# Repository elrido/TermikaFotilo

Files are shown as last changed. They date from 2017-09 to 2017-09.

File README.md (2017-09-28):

Termika Fotilo
==============

Termika Fotilo is Esperanto for thermal camera. The project, published in
[Make: Magazin 3/2017 on page 16](https://www.heise.de/select/make/2017/3/1498421900241703), 
describes a very limited infrared camera based on the relatively cheap (around
EUR 40) Melexis MLX90621 infrared sensor with a resolution of 16x4 pixels.

Origin
------

This is in turn inspired by the [DIY-Thermocam of Max Ritter](http://www.diy-thermocam.net/)
which was presented on the Maker Faire 2016 in Berlin. Ritter's kit uses a Flir
Lepton 3 infrared sensor with a resolution of 160x120 pixels (with a Lepton 2.5
the resolution is 80x60). That sensor is a lot better, but also much more expensive.

Finally, this repository aims to port the Termika Fotilo sketchbook, written for
use with an Arduino Nano, over to the ESP8266 plattform. It may be used with so
called dev boards, like the NodeMCU, which already comes with a voltage regulator
for a powering over USB or a battery pack, but these files are provided with use
of a bare ESP-12-E or ESP-12-F in mind (ESP-7 or earlier ESP-12 revisions should
work, but are untested: check your pinout diagrams).

Motivation
----------

If you do have a Arduino Nano at hand, then please just go for the Make: Magazin
article, which has very detailed instructions how to set up and may be purchased
for just EUR 3.29 as a PDF, in case you do not own that issue of the magazine.

The reason I am using an ESP chip instead is simply because I have them
already lying around, they are dirt cheap (currently around USD 1.70) and even
more compact then an Arduino Nano. The downside is that when using a bare ESP we
do have to add a few components for getting some pins to the right level on boot,
for voltage stability and of course the whole WiFi part of the ESP goes completely
unused.

Schema
------

Here below is schema showing how to set this up with a bare, flashed ESP chip.
When using a NodeMCU, the schema from the Make: article can be applied,
obviously choosing the appropriate SPI- and I²C-pins of the NodeMCU.

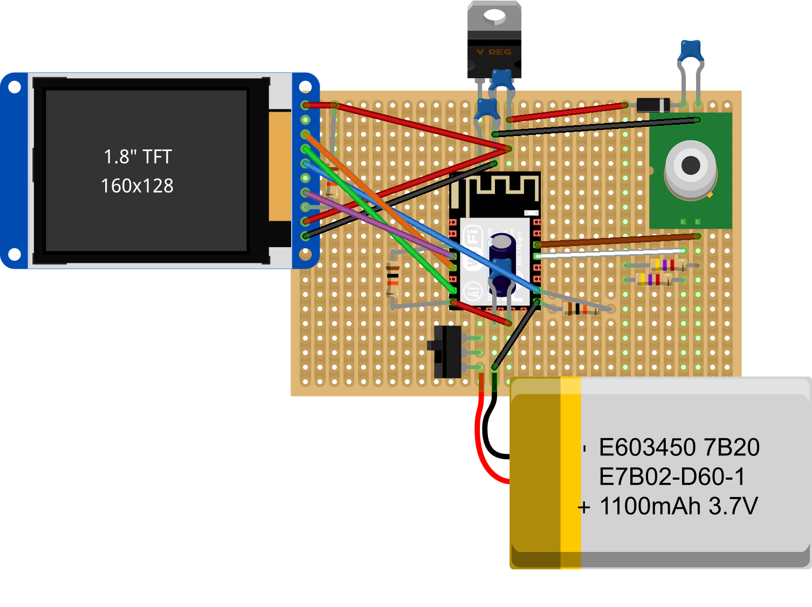
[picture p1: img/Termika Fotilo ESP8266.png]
Termika Fotilo schema using an ESP8266


Result
------

Backside before soldering on the screen:

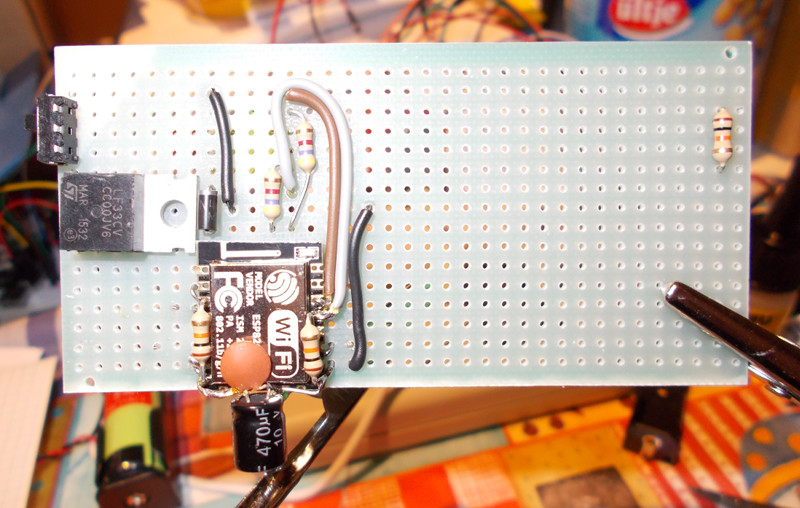
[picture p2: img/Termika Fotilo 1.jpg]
Termika Fotilo backside before soldering on the screen


Backside with screen soldered on:

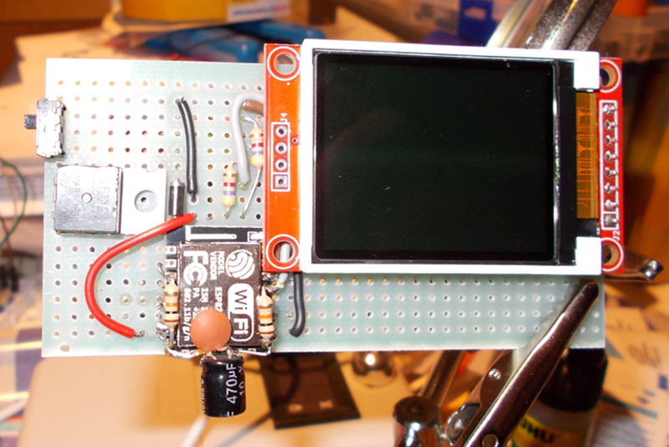
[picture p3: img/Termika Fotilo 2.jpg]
Termika Fotilo backside with screen soldered on


Front before attaching the battery:

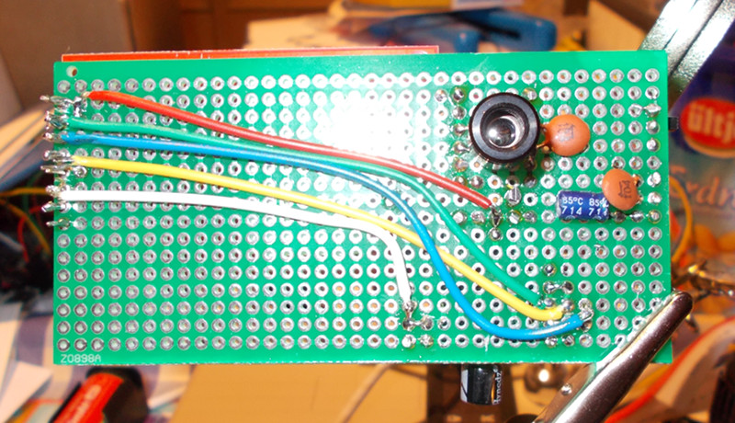
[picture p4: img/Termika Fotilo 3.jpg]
Termika Fotilo front before attaching the battery


Front with battery and USB charging board attached:

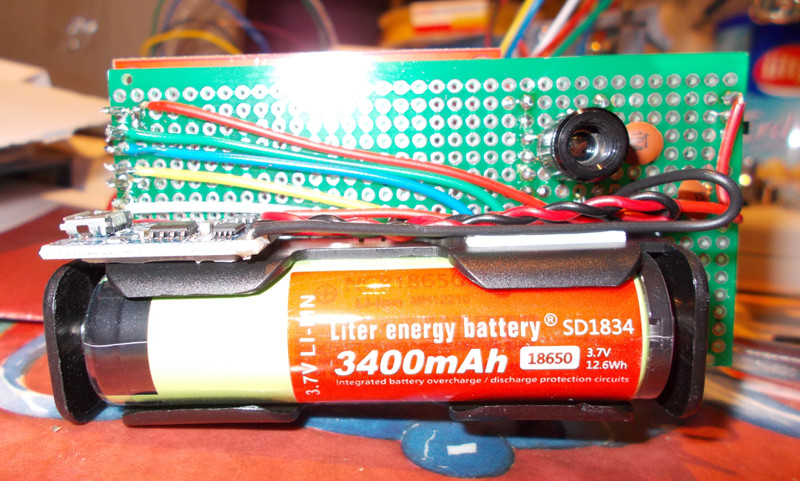
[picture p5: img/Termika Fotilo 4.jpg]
Termika Fotilo front with battery and USB charging board attached


Note that these photos show the reference pin of the sensor in the wrong
position. The correct orientation of the pin is to the left and not towards the
top of the sensor. Unfortunately I did not notice this in my tests before
soldering the sensor on.

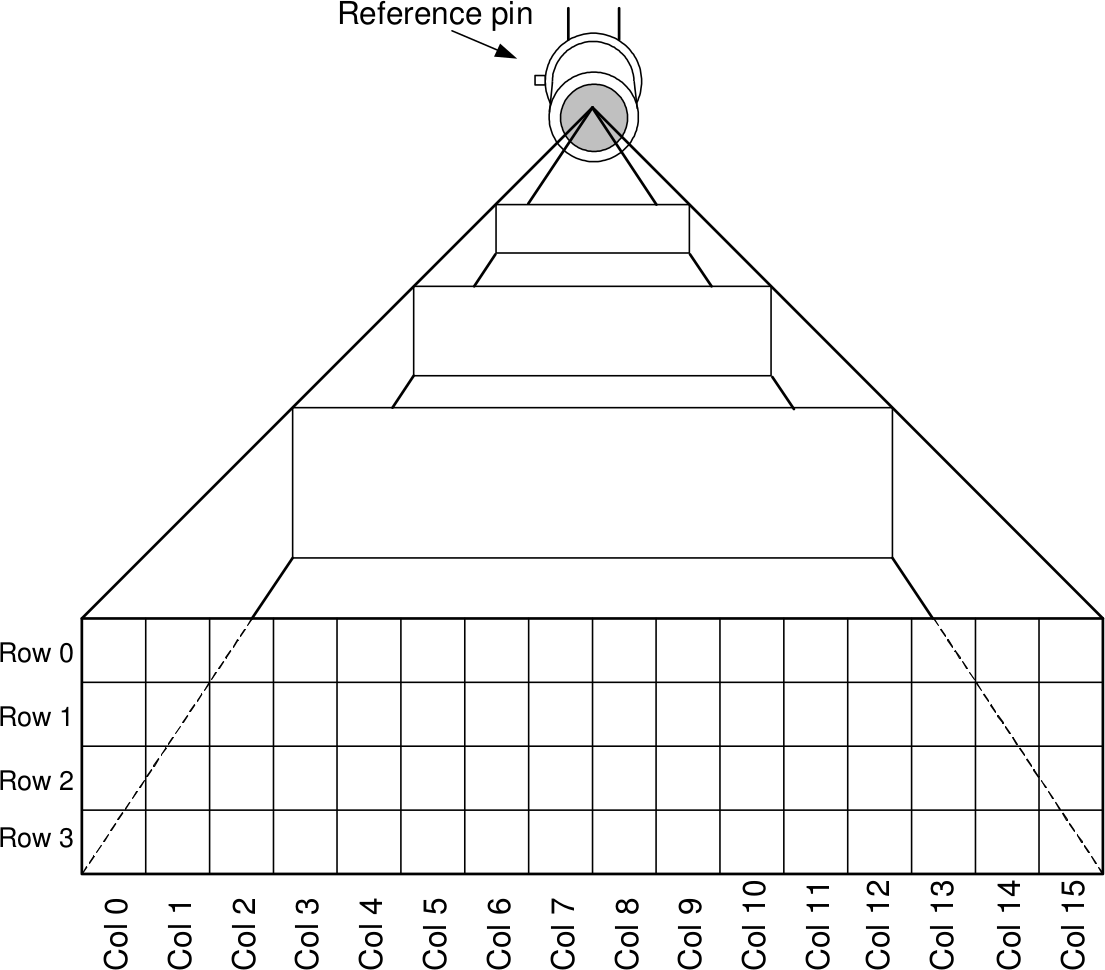
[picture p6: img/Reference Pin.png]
MLX90621 reference pin orientation


License
-------

I did not find any license information on the source code provided by Make:
Magazin, but assume that it is copyrighted by Felix Pfeifer and Florian
Schäffer, authors of the article in the magazine, and/or Maker Media GmbH.

Therefore this project is provided on the same conditions and I assume it is
required to legally own a copy of at least the article to make any use of it.

By no means is the publishing of this code in this repository meant to infringe
on this copyright or to imply that this code is under public domain or may be
used commercially. This is shared in good faith under the assumption that it is
used for fun or education by readers of the Make: Magazin.

Note that this repository is not hosted in Germany and the I do not live in that
jurisdiction either. According to my jurisdiction, if you take any offence to me
publishing this, you need to inform me (send an email to elrido@gmx.net) and I
will gladly comply and remove this content, but I am not liable for any
imaginary damage that this publication may be believed to have done or any other
made up lawyer costs (like that "Abmahnung" lunacy) that might apply in German
jurisdiction. If any actual damage was done and bad faith on my side can be
proven, then of course you may take me to court. But before that, lets be civil
and just solve the problem as outlined above, without feeding the trolls (lawyers).

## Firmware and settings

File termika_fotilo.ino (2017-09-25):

/*
 * Termika Fotilo
 * Make: IV/2017
 * 
 * Arduino Nano mit LCD 128x160 (ST7735) und MLX90621 als Waermebildkamera
 * 
 * ACHTUNG!
 * In den Libraries 
 * \arduino\hardware\arduino\avr\libraries\Wire\src\Wire.h und
 * \arduino\hardware\arduino\avr\libraries\Wire\src\utility\twi.h
 * muessen unbedingt die #defines fuer
 * BUFFER_LENGTH und
 * TWI_BUFFER_LENGTH
 * auf den Wert 64 geandert werden
 * 
 * Zwei Warning-Ausgaben beim compilieren sind normal, weil die SD-Karte auf dem Display nicht genutzt wird
 * 
 */
 
#include <ESP8266WiFi.h>
#include "Adafruit_ST7735.h"
#include "termika_fotilo.h"
#include "mlx90621.h"

Adafruit_ST7735 TFTscreen = Adafruit_ST7735(CS_, DC_, RST_);    // TFT Konstruktor
MLX90621 MLXtemp;                       // Objekt fuer Tempsensor erzeugen

void setup() {
  StartScreen();
  while (!MLXtemp.init())        // MLX90620 init failed
    delay (100);
}

void loop()   // endlos
{
  OutAmbientTemp();
  OutTempField();
  delay(100);         // etwas weniger Stress
}

/**
  @brief  Zeichnet den Grundaufbau auf das Display
  @param  none
  @return none
*/
void StartScreen(void)
{
  uint8_t i;
  float R, G, B;
  float gradstep;
  char puffer[10];

  TFTscreen.initR(INITR_BLACKTAB);
  TFTscreen.setRotation(1);
  TFTscreen.background (0, 0, 0);

  TFTscreen.stroke (0xFF, 0xFF, 0);
  TFTscreen.fill (50, 100, 200);
  TFTscreen.rect (0, 0, 159, 20);          // Titelkasten

  TFTscreen.stroke (255,0,0);
  TFTscreen.setTextSize (2);
  TFTscreen.text ("Make:",100,3);     // 5x7 Font x2

  TFTscreen.stroke (0xFF , 0xFF, 0xFF);
  TFTscreen.setTextSize (1);
  TFTscreen.text ("TERMIKA FOTILO",3,7);

  TFTscreen.stroke (0xFF, 0x50, 0x50);
  TFTscreen.setTextSize (1);
  TFTscreen.text ("Init...", 0, 112);
  TFTscreen.text ("Please wait", 0, 120);


  TFTscreen.stroke (127, 127, 127);
  TFTscreen.fill (0, 0, 100);
  TFTscreen.rect (0, 27, 16+2, 4+2);                    // Original Daten
  TFTscreen.rect (0, 40, 16*ZOOM+2, 4*ZOOM+2);          // Daten xZOOM
  TFTscreen.rect (0, 75, 15*ZOOM+2, 3*ZOOM+2);      // Daten xZOOM interpoliert

  for (i=0; i < 103; i++)                 // 103 Farb-Schritte werden angezeigt
  {
    HSVtoRGB (R, G, B, i * (HUEMAX/103.0), 1, .5);        // 320/103  
    TFTscreen.stroke (R * 255, G * 255, B * 255);
    TFTscreen.line (150, i+25, 159, i+25);
  }

  TFTscreen.stroke (0xFF , 0xFF, 0xFF);
  TFTscreen.setTextSize (1);
  
  itoa (MINTEMP, puffer, 10);
  TFTscreen.text (puffer, 130, 120);
  
  itoa (MAXTEMP, puffer, 10);
  TFTscreen.text (puffer, 130, 25);        // => 150+20 = 170 Grad-Schritte umfasst der Farbbalken => bei 102 Farb-Schritte = 170/103 = 1,65 °C/Farb-Schritt

  // Zero degree line
  gradstep = (MAXTEMP + abs(MINTEMP)) / 103.0;      // Absoultwert von Min
  i = 25 + (uint8_t)(MAXTEMP / gradstep);
  TFTscreen.line (145, i, 150, i);
}

/**
  @brief  Schreibt die Umgebungstemperatur des Chips aufs Display
  @param  none
  @return none
*/
void OutAmbientTemp(void)
{
  float t = MLXtemp.get_ptat();
  char puffer[10];

  TFTscreen.stroke (0, 0, 0);
  TFTscreen.fill (0, 0, 0);
  TFTscreen.rect (0, 112, 70, 128-112);          // Alte Zahl loeschen

  TFTscreen.stroke (0xFF, 0xFF, 0);
  TFTscreen.setTextSize (2);

  dtostrf (t, 6, 1, puffer);
  TFTscreen.text (puffer, 0, 112);     // 5x7 Font x2
  TFTscreen.setTextSize (1);
  TFTscreen.text ("\xF7", 74, 112);     // "°C" ASCII 0xF7 fuer Gradzeichen
  TFTscreen.text ("C", 80, 112);    
}

/**
  @brief  Konvertiert einen HDV-Farbwert in RGB um (http://wisotop.de/rgb-nach-hsv.php)
  @param  RGB-Werte als Call by reference (0..1)
          H = 0..360
          S = 0..1
          V = 0..1
  @return none
*/
void HSVtoRGB(float &r, float &g, float &b, float h, float s, float v) 
{
   int i;
   float f, p, q, t;
   if( s == 0 ) { // achromatisch (Grau)
      r = g = b = v;
      return;
   }
   h /= 60;           // sector 0 to 5
   i = floor( h );
   f = h - i;         // factorial part of h
   p = v * ( 1 - s );
   q = v * ( 1 - s * f );
   t = v * ( 1 - s * ( 1 - f ) );
   switch( i ) {
      case 0: r = v; g = t; b = p; break;
      case 1: r = q; g = v; b = p; break;
      case 2: r = p; g = v; b = t; break;
      case 3: r = p; g = q; b = v; break;
      case 4: r = t; g = p; b = v; break;
      default:  // case 5:
         r = v; g = p; b = q; break;
   }
}

/**
  @brief  Grafische Ausgabe
  @param  none
  @return none
*/
void OutTempField(void)
{
  int8_t x, y, xmod, xorg1, xorg2, ymod, yorg1, yorg2; //, xz, yz;
  float temps[16][4];
  float i, i1, i2;
  float hue;
  float R, G, B;
  float interpoltemp;
  
  MLXtemp.read_all_irfield (temps);

  // Reihe umkehren, da Sensor nach vorne und Display nach hinten => Temperatur-Feld so wie, auf Display zu zeigen
  for (y = 0; y < 4; y++)
  {
    for (x = 0; x < 8; x++)       
    {
      i = temps[15 - x][y];                       // Wert von rechts retten
      temps[15 - x][y] = temps[x][y];
      temps[x][y] = i;
    }
  }

  // Ausgabe des Temperaturfeldes auf Display
  for (y = 0; y < 4; y++)
  {
    for (x = 0; x < 16; x++)       
    {
      hue = HUEMAX - (temps[x][y] + abs(MINTEMP)) * (HUEMAX / (float)(MAXTEMP + abs(MINTEMP)));
      HSVtoRGB (R, G, B, hue, 1, .5);        
      TFTscreen.stroke (R * 255, G * 255, B * 255);
      TFTscreen.fill (R * 255, G * 255, B * 255);

      TFTscreen.point (x + 1, y + 28);                                // 1:1 Datenfeld
      TFTscreen.rect (x * ZOOM + 1, y * ZOOM + 41, ZOOM, ZOOM);       // Daten xZOOM
    }
  }

  // Ausgabe interpolierte Werte (Problemloesung durch viel Rechnezeit, da wenig Speicher)
  for(x = 0; x < (ZOOM * 15); x++)
  {
    for(y = 0; y < (ZOOM * 3); y++)
    {
      xmod = x % ZOOM;
      xorg1 = x - xmod;
      xorg2 = xorg1 + ZOOM;
      ymod = y % ZOOM;
      yorg1 = y - ymod;
      yorg2 = yorg1 + ZOOM;
      i1 = LinInterpol (temps[x / ZOOM][y / ZOOM], temps[x / ZOOM + 1][y / ZOOM], xorg1 , xorg2, x);                  // horizontale Interpolation Ausgangsdaten Zeile n
      i2 = LinInterpol (temps[x / ZOOM][y / ZOOM + 1], temps[x / ZOOM + 1][y / ZOOM + 1], xorg1 , xorg2, x);          // horizontale Interpolation Ausgangsdaten Zeile n+1
      interpoltemp = LinInterpol (i1, i2, yorg1, yorg2, y);                                                           // vertikale Interpolation

      hue = HUEMAX - (interpoltemp + abs(MINTEMP)) * (HUEMAX / (float)(MAXTEMP + abs(MINTEMP)));
      HSVtoRGB (R, G, B, hue, 1, .5);        
      TFTscreen.stroke (R * 255, G * 255, B * 255);
      TFTscreen.fill (R * 255, G * 255, B * 255);
      TFTscreen.point (x + 1, y + 75 + 1);                    // interpol. Pixel
    }
  }
}

/**
  @brief  Fuehrt lineare Interpolation durch
  @param  x1 <= x <= x2
          t1, t2 Temperatur
  @return interpolierte Temperatur fuer x
*/
float LinInterpol (float t1, float t2, uint8_t x1, uint8_t x2, uint8_t x)
{
  return t1 * (x2 - x) / ZOOM + t2 * (x - x1) / ZOOM;
}

/**
  @brief  Ermittler kleinste Temperatur
  @param  Temp-Feld
  @return Minimum
*/
float FindMinTemp (float temperatures[])
{
  uint8_t i;
  float temp = 300.0;     // maximal possible Temp

  for (i = 0; i < 64; i++)
  {
    if (temperatures[i] < temp)
      temp = temperatures[i];
  }

  return temp;
}

/**
  @brief  Ermittler hoechste Temperatur
  @param  Temp-Feld
  @return Maximoum
*/
float FindMaxTemp (float temperatures[])
{
  uint8_t i;
  float temp = -20.0;     // min. possible Temp

  for (i = 0; i < 64; i++)
  {
    if (temperatures[i] > temp)
      temp = temperatures[i];
  }

  return temp;
}

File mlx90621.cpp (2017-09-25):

/*
 * Library für MLX90621 IT-Sensor
 * 
 * Andere Typen sind aehnlich aber nutzen andere Berechnung
 * 
 * ACHTUNG!
 * In der Library Wire.h muss unbedingt der #defines fuer BUFFER_LENGTH auf den Wert
 * 64 geandert werden. Ansonsten ist der Buffer zum empfangen von I2C-Daten zu klein
 */

#include "mlx90621.h"

/**
  @brief  Initialisiert den Sensor. Einmal zu Beginn
  @param  none
  @return 0 = Fehler, 1 = OK
*/
uint8_t MLX90621::init (void)
{
  Wire.begin();     // join i2c bus 
  delay(5);   // erst ab 5ms nach power on reset POR
 
  if (!read_eeprom()) 
    return 0;
  write_trim (eepromMLX[0xF7]);                       // Trimwert im EEPROM-Inhalt Adresse 0xF7
  write_config (eepromMLX[0xF5], eepromMLX[0xF6]);    // Normal mode (no sleep), I2C FM+ mode enabled, ADC low reference enabled 

  configreg = read_config();

  ta = get_ptat();      
  if (ta > 300 || ta < -20)      // out of bounds, wichtig zu pruefen
    return 0;

  vcp = read_compensation();                                  // Compensation pixel 

  acp = (int16_t)( eepromMLX[0xD4] << 8 ) | eepromMLX[0xD3];           // Compensation pixel individual offset coefficient
  bcpee = (int8_t)eepromMLX[0xD5];                                      // Individual Ta dependence (slope) of the compensation pixel offset
  tgc = (int8_t)eepromMLX[0xD8];                                      // Thermal gradient coefficient
  aiscale = eepromMLX[0xD9] >> 4;                             // [7:4] – Scaling coeff for the IR pixels offset
  biscale = eepromMLX[0xD9] & 0x0F;                           // [3:0] – Scaling coeff of the IR pixels offset Ta dependence
  alpha0 = ( eepromMLX[0xE1] << 8 ) | eepromMLX[0xE0];        // Common sensitivity coefficient of IR pixels
  alpha0scale = eepromMLX[0xE2];                              // Scaling coefficient for common sensitivity
  deltaalphascale = eepromMLX[0xE3];                          // Scaling coefficient for individual sensitivity
  alphacp = (( eepromMLX[0xD7] << 8 ) | eepromMLX[0xD6]) / (float) (pow (2, alpha0scale) * pow (2, 3 - ( (configreg >> 4) & 0x03)));       // Sensitivity coefficient of the compensation pixel
  epsilon = ( eepromMLX[0xE5] << 8 ) | eepromMLX[0xE4] ;       // Emissivity
  acommon = (int16_t)(( eepromMLX[0xD1] << 8 ) | eepromMLX[0xD0]);    // IR pixel common offset coefficient
  ksta = (int16_t)(( eepromMLX[0xD7] << 8 ) | eepromMLX[0xD6]);   // KsTa (fixed scale coefficient = 20)
  ks4ee = (int8_t)eepromMLX[0xC4];
  ksscale = eepromMLX[0xC0];
  
  return 1;
}

/**
  @brief  Liest das IR-Feld einmal aus und berechnet die Temperaturen fuer jeden einzelnen IR-Sensor => temperatures[]
  @param  none
  @return none
*/
void MLX90621::read_all_irfield (float temperatures[16][4])
{
  uint8_t x, y, i;
  int16_t vir;
  uint8_t deltaai;               // IR pixel individual offset coefficient
  int8_t bieeprom;
  float bi;               // Individual Ta dependence (slope) of IR pixels offset
  float bcp;
  uint8_t deltaalpha;      // Individual sensitivity coefficient
  float viroffsetcompensated;     //
  float virtgccompensated;
  float vircpoffsetcompensated;
  float vircompensated;
  float ai;
  float alphacomp;
  float alpha;
  float ks4;
  uint64_t tak4;
  float sx;
  float to;
  
  while (test_por ())
  {
    delay (10);
    init ();
  }

   if (!read_ir ())
     return;
    
  for (i = 0; i < 64; i++)
  {
    vir = (int16_t)(irpixels[i * 2 + 1] << 8 | irpixels[i * 2]);      
    deltaai = eepromMLX[i];
    bi = (int8_t)eepromMLX[0x40 + i];   
    deltaalpha = eepromMLX[0x80 + i]; 

    // 7.3.3.1 
    // Offset compensation
    ai = (acommon + deltaai * pow (2, aiscale)) / pow (2, ( (configreg >> 4) & 0x03));      // Bit 5:4 Config Register
    bi = bi / (pow (2, biscale) * pow (2, 3 - ( (configreg >> 4) & 0x03)));
    viroffsetcompensated = vir - (ai + bi * (ta - 25.0));

    // Thermal Gradient Compensation (TGC)
    bcp = bcpee / (pow (2, biscale) * pow (2, 3 - ( (configreg >> 4) & 0x03)));
    vircpoffsetcompensated = vcp - (acp + bcp * (ta - 25.0) );
    virtgccompensated = viroffsetcompensated - ( (tgc / 32.0) *  vircpoffsetcompensated);

    // Emissivity compensation
    vircompensated = virtgccompensated / (epsilon / 32768);
    
    // 7.3.3.2
    alpha = ( ( alpha0 / pow (2, alpha0scale) ) + ( deltaalpha / pow (2, deltaalphascale) ) ) / (float) pow (2, 3 - ( (configreg >> 4) & 0x03)) ;
    alphacomp = (1 + (ksta/pow (2, 20)) * (ta - 25.0)) * (alpha - tgc * alphacp);

    // 7.3.3.1
    ks4 = ks4ee / pow (2, ksscale + 8);
  
    // 7.3.3
    tak4 = pow ( (ta + 273.15), 4);
    sx = ks4 * pow ( ( ( pow (alphacomp, 3) * vircompensated ) + ( pow  ( alphacomp, 4 ) * tak4 ) ), (1 / 4.0) );              // x. Wurzel aus y = y^(1/x)
    to = pow ( (vircompensated / ( alphacomp * (1 - ks4 * 273.15) + sx ) ) + tak4, (1 / 4.0) ) - 273.15;

    temperatures[i%16][(uint8_t)i/16] = to;      // yeah, wir haben die reale Temperatur
  }
}

/**
  @brief  Liest 64 Bytes aus dem EEPROM und speichert diese in eepromMLX
  @param  Startadresse
  @return none
*/
uint8_t MLX90621::read_eeprom_64 (uint8_t start)
{
  uint16_t i;

  Wire.beginTransmission(eeprom_dump_address);      // Adresse des Chips: Whole EEPROM dump
  Wire.write (start);                                // Command: Read the whole EEPROM (start address)
  Wire.endTransmission(0);
  
  if (!Wire.requestFrom(eeprom_dump_address, (uint8_t) 64) ) 
    return 0;      // receive 64 Bytes. Wire.h kann eigentlich nur 32
    
  for (i = start; i < (start + 64); i++)
    eepromMLX[i] = Wire.read();

  return 1;
}

/**
  @brief  Liest 256 Bytes aus dem EEPROM und speichert die Daten in eepromMLX
  @param  none
  @return none
*/
uint8_t MLX90621::read_eeprom (void)
{
  uint16_t i;

  if (!read_eeprom_64 (0x00))
    return 0;
  if (!read_eeprom_64 (0x40))
    return 0;
  if (!read_eeprom_64 (0x80))
    return 0;
  if (!read_eeprom_64 (0xC0))
    return 0;

  return 1;
}

/**
  @brief  Speichert den Oszillator-Trim-Wet aus dem EEPROM (HSB immer 0)
  @param  Trimwert
  @return none
*/
void MLX90621::write_trim (uint8_t trimvalue)
{
  Wire.beginTransmission(chip_address);       // Adresse des Chips zum speichern des Trimwertes
  Wire.write (0x04);                          // Command: write trim value
  Wire.write (trimvalue - 0xAA);              // LSByte check
  Wire.write (trimvalue);                     // LSB
  Wire.write (0x00 - 0xAA);                   // HSByte check
  Wire.write (0x00);                          // HSB/MSB
  Wire.endTransmission();
}
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

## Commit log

2017-09-25 Wire lib on the ESP may only be started during setup, reverting BGR back to RGB
    [Wire.cpp, mlx90621.cpp, termika_fotilo.ino]
2017-09-25 removing debug code and fixing indentation
    [mlx90621.cpp, termika_fotilo.ino]
2017-09-28 adding fritzing schema
    [Termika Fotilo ESP8266.fzz]
2017-09-28 documenting reference pin orientation
2017-09-28 cleanup & layout
    [Termika Fotilo ESP8266.fzz]
